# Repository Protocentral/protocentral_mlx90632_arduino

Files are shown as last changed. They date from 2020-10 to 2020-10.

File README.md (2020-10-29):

## Protocentral MLX90632

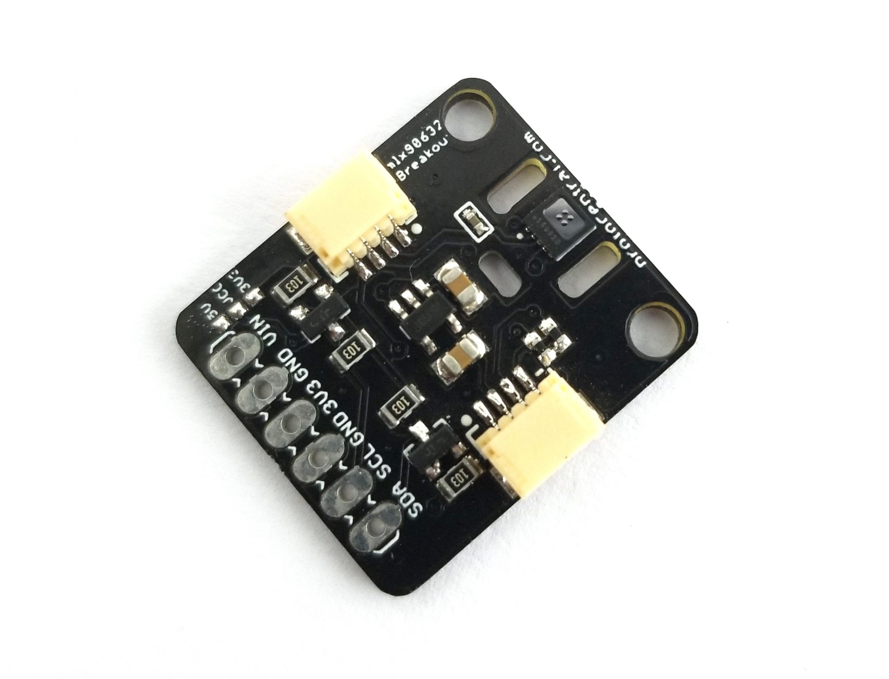
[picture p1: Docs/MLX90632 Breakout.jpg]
Temperature sensor breakout


**ProtoCentral Infrared Non-Contact Thermometer (Qwiic) – MLX90632** is a miniature breakout for accurate non-contact temperature measurement, especially in thermally challenging environments.

It supports any microcontroller for interface with the integrated logic level converter on-board regulator and now compatible with an integrated QWIIC-connectors for complete compatibility with the QWIIC Ecosystem The temperature measured by MLX90632 is the average temperature of all the objects in its field of view. The wavelength pass band of the optical filter integrated into the sensor ranges from 2 to 14Î¼m.This board is directly compatible with the QWIIC connector standard from Sparkfun. This means easy plug-and-play usage with all QWIIC-compatible shields and boards.

### Connection with Arduino

|Protocentral MLX90632 pin label| Arduino Connection |Pin Function |
|--- |:---:|---:|
| SDA | A4 |  Serial Data |
| SCL | A5 |  Serial Clock |
| Vin | 5V |  Power |
| GND | Gnd |  Gnd |

License Information
===================

This product is open source! Both, our hardware and software are open source and licensed under the following licenses:

Hardware
---------

**All hardware is released under [Creative Commons Share-alike 4.0 International](http://creativecommons.org/licenses/by-sa/4.0/).**


You are free to:

* Share — copy and redistribute the material in any medium or format
* Adapt — remix, transform, and build upon the material for any purpose, even commercially.
The licensor cannot revoke these freedoms as long as you follow the license terms.

Under the following terms:

* Attribution — You must give appropriate credit, provide a link to the license, and indicate if changes were made. You may do so in any reasonable manner, but not in any way that suggests the licensor endorses you or your use.
* ShareAlike — If you remix, transform, or build upon the material, you must distribute your contributions under the same license as the original.

Software
--------

**All software is released under the MIT License(http://opensource.org/licenses/MIT).**

THE SOFTWARE IS PROVIDED "AS IS", WITHOUT WARRANTY OF ANY KIND, EXPRESS OR IMPLIED, INCLUDING BUT NOT LIMITED TO THE WARRANTIES OF MERCHANTABILITY, FITNESS FOR A PARTICULAR PURPOSE AND NONINFRINGEMENT. IN NO EVENT SHALL THE AUTHORS OR COPYRIGHT HOLDERS BE LIABLE FOR ANY CLAIM, DAMAGES OR OTHER LIABILITY, WHETHER IN AN ACTION OF CONTRACT, TORT OR OTHERWISE, ARISING FROM, OUT OF OR IN CONNECTION WITH THE SOFTWARE OR THE USE OR OTHER DEALINGS IN THE SOFTWARE.

Please check [*LICENSE.md*](LICENSE.md) for detailed license descriptions.

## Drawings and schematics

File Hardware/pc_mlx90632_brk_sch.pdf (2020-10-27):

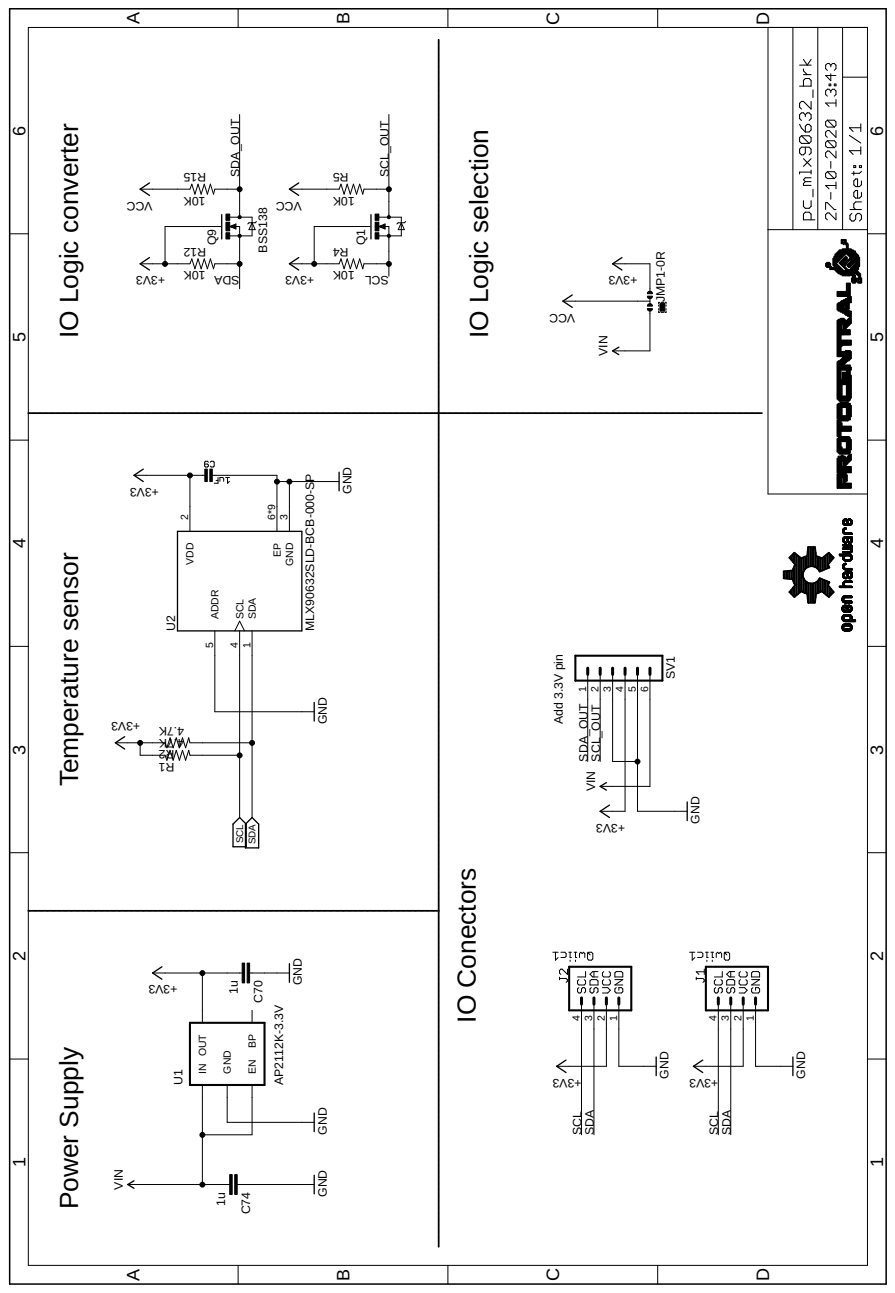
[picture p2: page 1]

IO Logic selection IO Logic converter Temperature sensor IO Conectors Power Supply GND 3V3+ GND 1u 1uGND VIN AP2112K-3.3V K7. 4 K7. 4 3V3+ BSS138 K01 K01 3V3+ K01 K01 3V3+ GND 3V3+ CCV VIN CCV CCV 3V3+ VIN GND GND 3V3+ 3V3+ MLX90632SLD-BCB-000-SP GND 3V3+ GND C70 C74 INGNOD UT EN BP U1 1 R2 R Q9 21 R 51 R Q1 4 R5 R 123456 SV1 JMP1-0R 43214321 SDA 1 VDD 2 GND 3 SCL 4 ADDR 5 EP 6*9 U2 L CS SCL SCL SCL ADS SDA SDA SDA SCL_OUT SCL_OUT SDA_OUT SDA_OUT ABCD 1 2 3 4 5 6 ABCD 1 2 3 4 5 6 Add 3.3V pin

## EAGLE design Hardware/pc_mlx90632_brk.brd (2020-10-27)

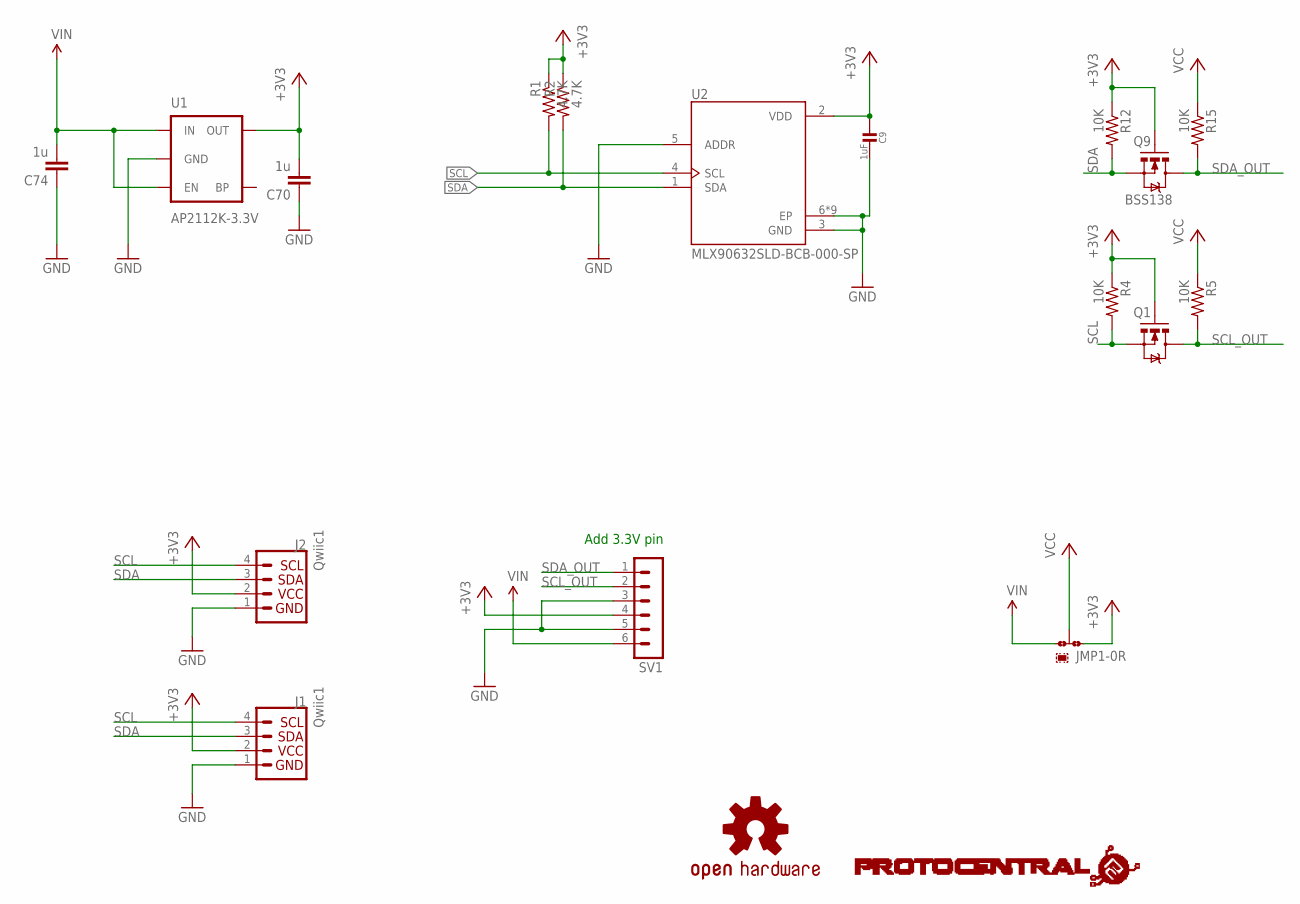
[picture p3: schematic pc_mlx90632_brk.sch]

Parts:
C9: 1uF; _0402
C70, C74: 1u; C0805
J1, J2: Qwiic1; 1X04_1MM_RA
JMP1: 0R-JUMPA; A0R-JMP-0402
Q1, Q9: BSS138; SOT23-3
R1, R2: 4.7K; R0402
R4, R5, R12, R15: 10K; 0805
SV1: MA06-1
U1: AP2112K-3.3V; SOT23-5
U2: MLX90632SLD-BCB-000-SP; XDCR_MLX90632SLD-BCB-000-SP
U$5: PROTY-LOGO; LOGO-PROTY
U$7: OSHW-LOGOS; OSHW-LOGO-S

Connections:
+3V3: C9.1, C70.2, J1.2, J2.2, JMP1.3, Q1.1 (G), Q9.1 (G), R1.1, R2.1, R4.1, R12.1, SV1.4, U1.5 (OUT), U2.2 (VDD)
GND: C9.2, C70.1, C74.1, J1.1, J2.1, SV1.3, SV1.5, U1.2 (GND), U2.3 (GND), U2.5 (ADDR), U2.6 (EP), U2.6.1 (EP), U2.6.2 (EP), U2.6.3 (EP), U2.6.4 (EP), U2.6.5 (EP), U2.6.6 (EP), U2.6.7 (EP), U2.6.8 (EP)
SCL: J1.4, J2.4, Q1.2 (S), R1.2, R4.2, U2.4 (SCL)
SCL_OUT: Q1.3 (D), R5.2, SV1.2
SDA: J1.3, J2.3, Q9.2 (S), R2.2, R12.2, U2.1 (SDA)
SDA_OUT: Q9.3 (D), R15.2, SV1.1
VCC: JMP1.2, R5.1, R15.1
VIN: C74.2, JMP1.1, SV1.6, U1.1 (IN), U1.3 (EN)

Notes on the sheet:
Add 3.3V pin

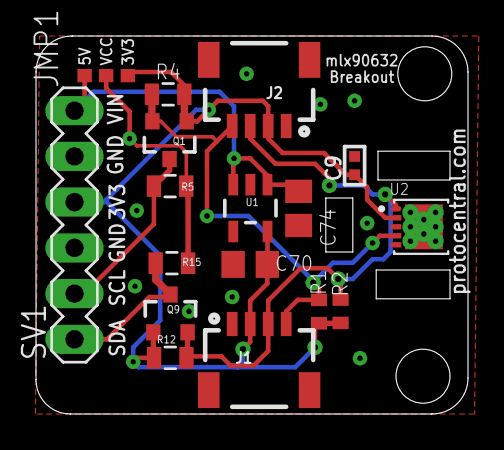
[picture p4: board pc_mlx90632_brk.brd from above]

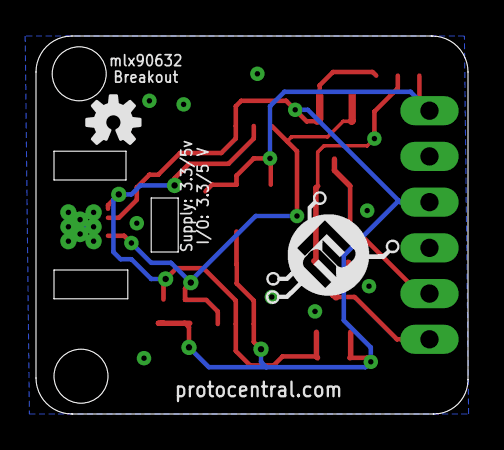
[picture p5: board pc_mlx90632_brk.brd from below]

Board: 4 copper layers, 24.0 x 21.0 mm, 19 parts (2 on the bottom side), 8 nets.

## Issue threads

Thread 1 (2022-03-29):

ProtoCentral MLX90632 Non-contact temperature Library not working with arduino due

Prabhupanneer, 2022-03-29:
Hi,
ProtoCentral MLX90632 Non-contact temperature Library not working with arduino due.
sensor not communicate with arduino due.

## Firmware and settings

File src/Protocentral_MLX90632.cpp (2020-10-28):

//////////////////////////////////////////////////////////////////////////////////////////
//
// Protocentral Arduino Library for  MLX90632 Non-contact temperature sensor
// If you have bought the breakout the connection with the Arduino board is as follows:
//
//|MLX pin label| Arduino Connection   |Pin Function      |
//|----------------- |:--------------------:|-----------------:|
//| SDA              |    A4               |  Serial Data      |
//| SCL              | A5                  |  Serial Clock     |
//| Vin              | 5V                  |  Power            |
//| GND              | Gnd                 |  Gnd              |
//
//
// Based on the original MLX90632 librry by Nathan Seidle, Sparkfun Electronics

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

#include "Protocentral_MLX90632.h"

double P_R;
double P_G;
double P_T;
double P_O;
double Ea;
double Eb;
double Fa;
double Fb;
double Ga;
double Gb;
double Ka;
double Ha;
double Hb;

double TOdut = 25.0; //Assume 25C for first iteration
double TO0 = 25.0; //object temp from previous calculation
double TA0 = 25.0; //ambient temp from previous calculation
double sensorTemp; //Internal temp of the MLX sensor

boolean Protocentral_MLX90632::begin()
{
  uint8_t deviceAddress = MLX90632_ADDRESS;
  TwoWire &wirePort = Wire;
  Protocentral_MLX90632::status returnError;
  if (begin(deviceAddress, wirePort, returnError) == true)
    return (true);
  return (false);
}

boolean Protocentral_MLX90632::begin(uint8_t deviceAddress, TwoWire &wirePort, status &returnError)
{
  returnError = SENSOR_SUCCESS;
  _deviceAddress = deviceAddress; //Get the I2C address from user
  _i2cPort = &wirePort; //Grab which port the user wants us to use

  uint16_t thisAddress;
  returnError = readRegister16(EE_I2C_ADDRESS, thisAddress);
  if (thisAddress != _deviceAddress >> 1)
  {
    if (_printDebug)
    {
      _debugPort->print(F("Error: Communication failure. Check wiring. Expected device address: 0x"));
      _debugPort->print(_deviceAddress, HEX);
      _debugPort->print(F(", instead read: 0x"));
      _debugPort->print(thisAddress << 1, HEX);
      _debugPort->println();
    }
    returnError = SENSOR_ID_ERROR;
    return (false); //Error
  }

  //Load all the static calibration factors
  int16_t tempValue16;
  int32_t tempValue32;
  readRegister32(EE_P_R, (uint32_t&)tempValue32);
  P_R = (double)tempValue32 * pow(2, -8);
  readRegister32(EE_P_G, (uint32_t&)tempValue32);
  P_G = (double)tempValue32 * pow(2, -20);
  readRegister32(EE_P_T, (uint32_t&)tempValue32);
  P_T = (double)tempValue32 * pow(2, -44);
  readRegister32(EE_P_O, (uint32_t&)tempValue32);
  P_O = (double)tempValue32 * pow(2, -8);
  readRegister32(EE_Ea, (uint32_t&)tempValue32);
  Ea = (double)tempValue32 * pow(2, -16);
  readRegister32(EE_Eb, (uint32_t&)tempValue32);
  Eb = (double)tempValue32 * pow(2, -8);
  readRegister32(EE_Fa, (uint32_t&)tempValue32);
  Fa = (double)tempValue32 * pow(2, -46);
  readRegister32(EE_Fb, (uint32_t&)tempValue32);
  Fb = (double)tempValue32 * pow(2, -36);
  readRegister32(EE_Ga, (uint32_t&)tempValue32);
  Ga = (double)tempValue32 * pow(2, -36);
  
  readRegister16(EE_Gb, (uint16_t&)tempValue16);
  Gb = (double)tempValue16 * pow(2, -10);
  readRegister16(EE_Ka, (uint16_t&)tempValue16);
  Ka = (double)tempValue16 * pow(2, -10);
  readRegister16(EE_Ha, (uint16_t&)tempValue16);
  Ha = (double)tempValue16 * pow(2, -14); //Ha!
  readRegister16(EE_Hb, (uint16_t&)tempValue16);
  Hb = (double)tempValue16 * pow(2, -14);

  return (true);
}

float Protocentral_MLX90632::getObjectTemp()
{
  Protocentral_MLX90632::status returnError;
  return (getObjectTemp(returnError));
}

float Protocentral_MLX90632::getObjectTemp(status& returnError)
{
  returnError = SENSOR_SUCCESS;

  if(getMode() != MODE_CONTINUOUS) setSOC();

  clearNewData();

  uint16_t counter = 0;
  while (dataAvailable() == false)
  {
    delay(1);
    counter++;
    if (counter == MAX_WAIT)
    {
      if (_printDebug) _debugPort->println(F("Data available timeout"));
      returnError = SENSOR_TIMEOUT_ERROR;
      return (0.0); 
    }
  }

  gatherSensorTemp(returnError);
  if (returnError != SENSOR_SUCCESS)
  {
    if (_printDebug)
    {
      _debugPort->println(F("Sensor temperature not found"));
      if(returnError == SENSOR_TIMEOUT_ERROR) _debugPort->println(F("Timeout"));
    }
    return (0.0); //Error
  }

 int16_t lowerRAM = 0;
  int16_t upperRAM = 0;

  int16_t sixRAM;
  readRegister16(RAM_6, (uint16_t&)sixRAM);
  int16_t nineRAM;
  readRegister16(RAM_9, (uint16_t&)nineRAM);

  //Object temp requires 3 iterations
  for (uint8_t i = 0 ; i < 3 ; i++)
  {
    double VRta = nineRAM + Gb * (sixRAM / 12.0);

    double AMB = (sixRAM / 12.0) / VRta * pow(2, 19);

    double sensorTemp = P_O + (AMB - P_R) / P_G + P_T * pow((AMB - P_R), 2);

    float S = (float)(lowerRAM + upperRAM) / 2.0;
    double VRto = nineRAM + Ka * (sixRAM / 12.0);
    double Sto = (S / 12.0) / VRto * (double)pow(2, 19);

    double TAdut = (AMB - Eb) / Ea + 25.0;

    double ambientTempK = TAdut + 273.15;

    double bigFraction = Sto / (1 * Fa * Ha * (1 + Ga * (TOdut - TO0) + Fb * (TAdut - TA0)));

    double objectTemp = bigFraction + pow(ambientTempK, 4);
    objectTemp = pow(objectTemp, 0.25); //Take 4th root
    objectTemp = objectTemp - 273.15 - Hb;
    TO0 = objectTemp;
  }

  return (TO0);
}

float Protocentral_MLX90632::getObjectTempF()
{
  float tempC = getObjectTemp();
  float tempF = tempC * 9.0/5.0 + 32.0;
  return(tempF);
}

float Protocentral_MLX90632::getSensorTemp()
{
  Protocentral_MLX90632::status tempFlag;
  return (getSensorTemp(tempFlag));
}

float Protocentral_MLX90632::getSensorTemp(status &returnError)
{
  returnError = SENSOR_SUCCESS;

  if(getMode() != MODE_CONTINUOUS) setSOC();

  clearNewData();

  uint16_t counter = 0;
  while (dataAvailable() == false)
  {
    delay(1);
    counter++;
    if (counter == MAX_WAIT)
    {
      returnError = SENSOR_TIMEOUT_ERROR;
      return (0.0); 
    }
  }

  return (gatherSensorTemp(returnError));
}

float Protocentral_MLX90632::gatherSensorTemp(status &returnError)
{
  returnError = SENSOR_SUCCESS;
  
  int16_t sixRAM;
  readRegister16(RAM_6, (uint16_t&)sixRAM);
  int16_t nineRAM;
  readRegister16(RAM_9, (uint16_t&)nineRAM);

  double VRta = nineRAM + Gb * (sixRAM / 12.0);

  double AMB = (sixRAM / 12.0) / VRta * pow(2, 19);

  double sensorTemp = P_O + (AMB - P_R) / P_G + P_T * pow((AMB - P_R), 2);

  return(sensorTemp);
}

bool Protocentral_MLX90632::dataAvailable()
{
  if (getStatus() & ((uint16_t)1 << BIT_NEW_DATA)) return (true);
  return (false);
}
void Protocentral_MLX90632::clearNewData()
{
  uint16_t reg = getStatus(); //Get current bits
  reg &= ~(1 << BIT_NEW_DATA); //Clear the bit
  writeRegister16(REG_STATUS, reg); //Set the mode bits
}

uint16_t Protocentral_MLX90632::getStatus()
{
  Protocentral_MLX90632::status returnError;
  return (getStatus(returnError));
}
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

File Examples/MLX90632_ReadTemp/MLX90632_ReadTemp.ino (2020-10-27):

//////////////////////////////////////////////////////////////////////////////////////////
//
//   Arduino Library for Protocentral MLX90632

// If you have bought the breakout the connection with the Arduino board is as follows:
//
//|MLX pin label| Arduino Connection   |Pin Function      |
//|----------------- |:--------------------:|-----------------:|
//| SDA              |    A4               |  Serial Data      |
//| SCL              | A5                  |  Serial Clock     |
//| Vin              | 5V                  |  Power            |
//| GND              | Gnd                 |  Gnd              |

/////////////////////////////////////////////////////////////////////////////////////////

#include "Protocentral_MLX90632.h"
#include <Wire.h>
Protocentral_MLX90632 ReadSensor;

void setup()
{
  Serial.begin(9600);
  Serial.println("Protocentral MLX90632 Read Data");

  Wire.begin();

  ReadSensor.begin();
}

void loop()
{
  float object_Temp = ReadSensor.getObjectTempF(); //Get the temperature of the object
  Serial.print("Object temperature: ");
  Serial.print(object_Temp, 2);
  Serial.print(" F");

  float sensor_Temp = ReadSensor.getSensorTemp(); //Get the temperature of the sensor
  Serial.print(" Sensor temperature: ");
  Serial.print(sensor_Temp, 2);
  Serial.print(" C");

  Serial.println();
}

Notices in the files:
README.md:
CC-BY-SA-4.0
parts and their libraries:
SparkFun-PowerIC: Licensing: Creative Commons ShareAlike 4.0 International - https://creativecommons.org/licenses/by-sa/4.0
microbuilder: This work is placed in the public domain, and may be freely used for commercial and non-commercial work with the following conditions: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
